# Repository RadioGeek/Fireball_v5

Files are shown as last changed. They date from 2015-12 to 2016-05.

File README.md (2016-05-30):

# Fireball_v5

<B>Compiling the Code</B>
<p>The Arduino IDE to compile and upload the code to the Fireball.  I've used the older v1.0.6 and latest
(current as of today) v1.6.8 IDE.  You will need to add the following board manager URL in the Arduino IDE Preferences, 
in order to successfully compile for the Atmel ATtiny85 processor:
https://raw.githubusercontent.com/damellis/attiny/ide-1.6.x-boards-manager/package_damellis_attiny_index.json

After you have added this to the board manager, goto Tools -> Board:, and select ATtiny at the bottom of the pulldown.
Then select the Tools menu again and you'll see additional options for Processor & Clock.
  Under the Tools -> Processor:, select ATtiny85.
  Under the Tools -> Clock:, select 8 MHz (internal)

Click the Verify button to confirm the code will compile.  If it does, you're ready to connect your AVR Programmer and
compile/upload the code.  I'm using an AVRISP mkII programmer, but I've also found my cheaper USBtinyISP purchased off
ebay worked just fine.  Sometimes you might have to select the Upload Using Programmer method, if the normal method fails.

DON'T FORGET TO BURN THE BOOTLOADER <B>BEFORE</B> UPLOADING THE CODE.</p>

<b>Config.h Settings</b>

<p>There are 3 lines in the config.h file that should be set based on user preference.</p>
<p>#define IDLE_BEEPS       true  // Enable short beeps on the second during idle time.  Set to either true or false. </p>
<p>#define SEND_CALL        true  // Enables sending of your callsign.  Set to either true or false. </p>
<p>#define CALLSIGN        "FB5"  // Operator's callsign.  Self explanatory, but can be anything less than 15 characters. </p>

<p> Have Fun with it!!!<p/>

John
AB5SS

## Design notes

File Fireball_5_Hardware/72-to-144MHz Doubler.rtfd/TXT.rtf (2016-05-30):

Design notes for constructing a 72 MHz to 144 MHz doubler

Circuit:
¬

Using 0402 SMD parts;
L = 68nH;
C (72MHz) = 72pF
C (144MHz) = 18pF

Using wire inductors and 18pf for C, calc L for 72 & 144 MHz:
Wire diameter = 0.025" & Coil Diameter = 0.25”
For 72 MHz, L = 271.5 nH; 8 turns, 0.25” length, spread for tuning;
For 144 MHz, L = 67.8 nH; 3 turns, no spacing but spread a little for tuning.

Calculator links:
http://www.daycounter.com/Calculators/Air-Core-Inductor-Calculator.phtml
http://www.1728.org/resfreq.htm

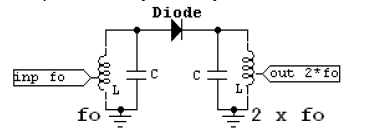
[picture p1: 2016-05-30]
Fireball_5_Hardware/72-to-144MHz Doubler.rtfd/Screen Shot 2015-04-06 at 9.13.16 AM.png

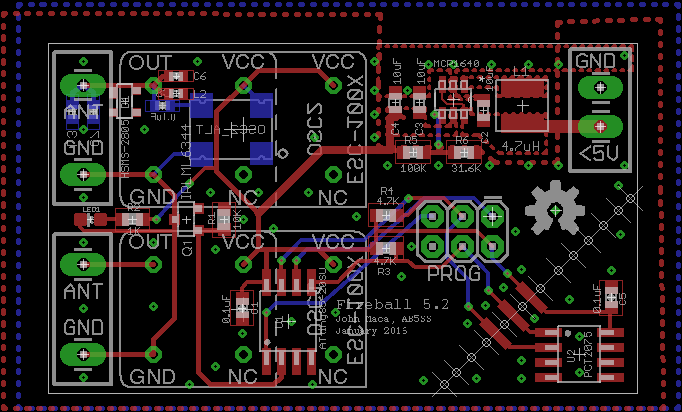
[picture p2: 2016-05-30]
Fireball_5_Hardware/Fireball_v5.2_AB5SS.brd.png

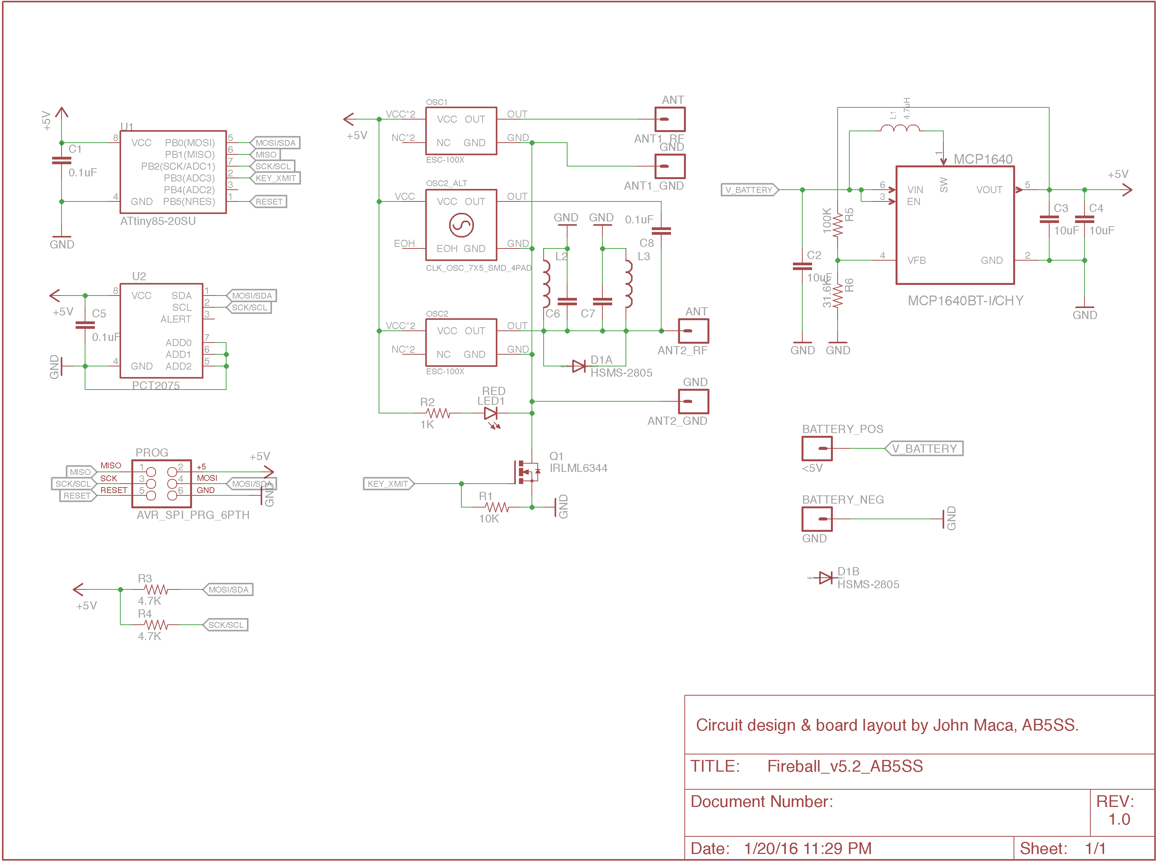
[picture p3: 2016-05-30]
Fireball_5_Hardware/Fireball_v5.2_AB5SS.sch.png

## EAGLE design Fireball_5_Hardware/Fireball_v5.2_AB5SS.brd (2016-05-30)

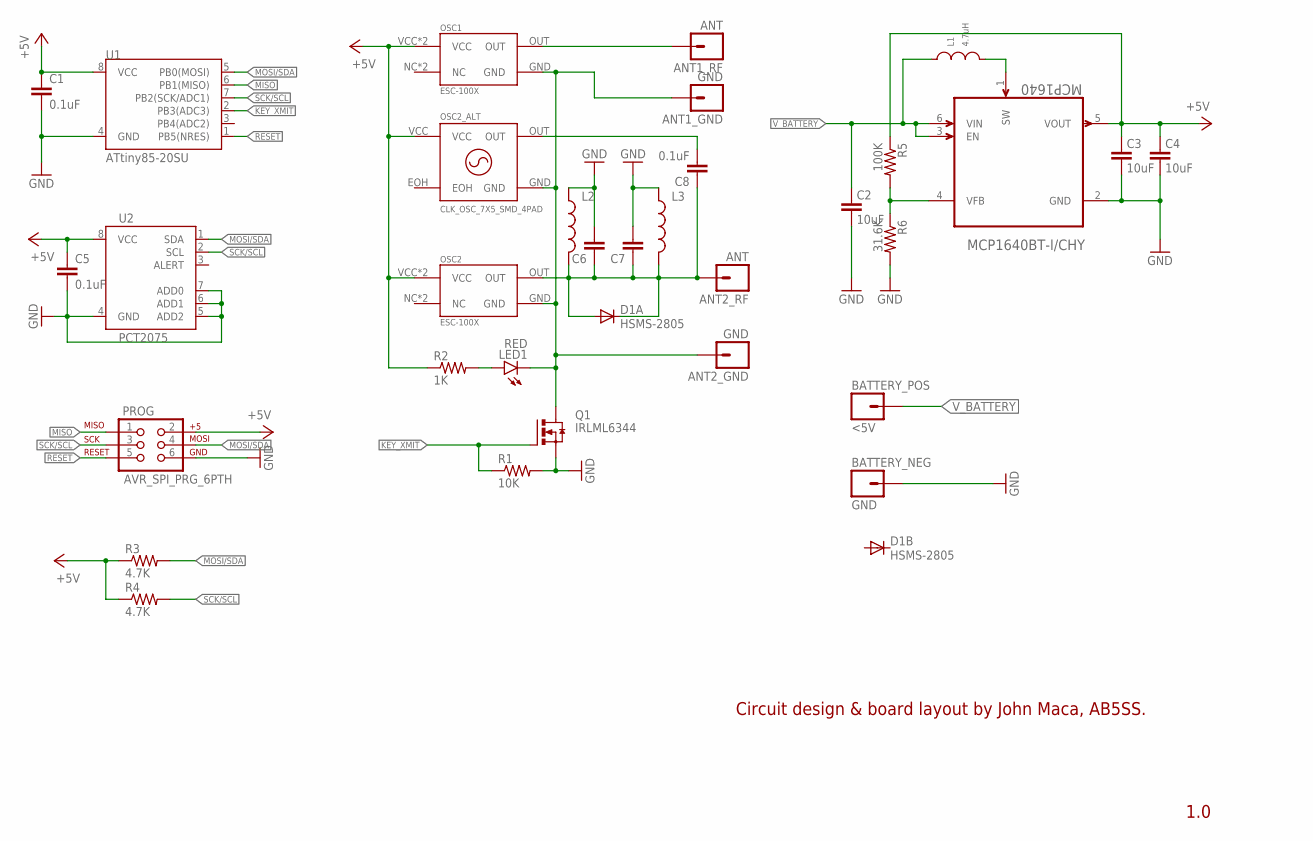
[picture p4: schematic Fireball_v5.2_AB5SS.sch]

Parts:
ANT1_GND, ANT2_GND: GND; 1X01_LONGPAD
ANT1_RF, ANT2_RF: ANT; 1X01_LONGPAD
BATTERY_NEG: GND; 1X01_LONGPAD
BATTERY_POS: <5V; 1X01_LONGPAD
C1, C5: 0.1uF; 0603-CAP
C2, C3, C4: 10uF; C603
C6, C7: CAP0402-CAP; 0402-CAP
C8: 0.1uF; 0402-CAP
D1: HSMS-2805; SOT143_AVAGO
L1: 4.7uH; SRN4026
L2, L3: INDUCTOR0402; C0402
LED1: RED; LED-0603
MCP1640: MCP1640BT-I/CHY; SOT95P270X145-6N
OSC1, OSC2: ESC-100X; OSC-20.86X13.2-4PIN
OSC2_ALT: CLK_OSC_7X5_SMD_4PAD; CLK_OSC_7.00X5.00_SMD-4PAD
PROG: AVR_SPI_PRG_6PTH; 2X3
Q1: IRLML6344; MICRO3
R1: 10K; 0603-RES
R2: 1K; 0603-RES
R3, R4: 4.7K; 0603-RES
R5: 100K; 0603-RES
R6: 31.6K; 0603-RES
U1: ATtiny85-20SU; SO08-EIAJ
U2: PCT2075; SO08

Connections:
+5V: C1.1, C3.1, C4.1, C5.1, MCP1640.5 (VOUT), OSC1.VCC, OSC1.VCC2 (VCC), OSC2.VCC, OSC2.VCC2 (VCC), OSC2_ALT.VCC, PROG.2, R2.1, R3.1, R4.1, R5.1, U1.8 (VCC), U2.8 (VCC)
GND: BATTERY_NEG.1, C1.2, C2.2, C3.2, C4.2, C5.2, C6.2, C7.2, L2.1, L3.1, MCP1640.2 (GND), PROG.6, Q1.2 (S), R1.2, R6.2, U1.4 (GND), U2.4 (GND), U2.5 (ADD2), U2.6 (ADD1), U2.7 (ADD0)
KEY_XMIT: Q1.1 (G), R1.1, U1.2 (PB3(ADC3))
L1_SW: L1.P$2 (2), MCP1640.1 (SW)
MISO: PROG.1, U1.6 (PB1(MISO))
MOSI/SDA: PROG.4, R3.2, U1.5 (PB0(MOSI)), U2.1 (SDA)
unnamed: ANT1_GND.1, ANT2_GND.1, LED1.C, OSC1.GND, OSC2.GND, OSC2_ALT.GND, Q1.3 (D)
unnamed: MCP1640.4 (VFB), R5.2, R6.1
unnamed: LED1.A, R2.2
unnamed: ANT1_RF.1, OSC1.OUT
unnamed: ANT2_RF.1, C6.1, C7.1, C8.1, D1.1 (C), D1.3 (A), L2.2, L3.2, OSC2.OUT
unnamed: C8.2, OSC2_ALT.OUT
RESET: PROG.5, U1.1 (PB5(NRES))
SCK/SCL: PROG.3, R4.2, U1.7 (PB2(SCK/ADC1)), U2.2 (SCL)
V_BATTERY: BATTERY_POS.1, C2.1, L1.P$1 (1), MCP1640.3 (EN), MCP1640.6 (VIN)

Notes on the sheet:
1.0
Circuit design & board layout by John Maca, AB5SS.

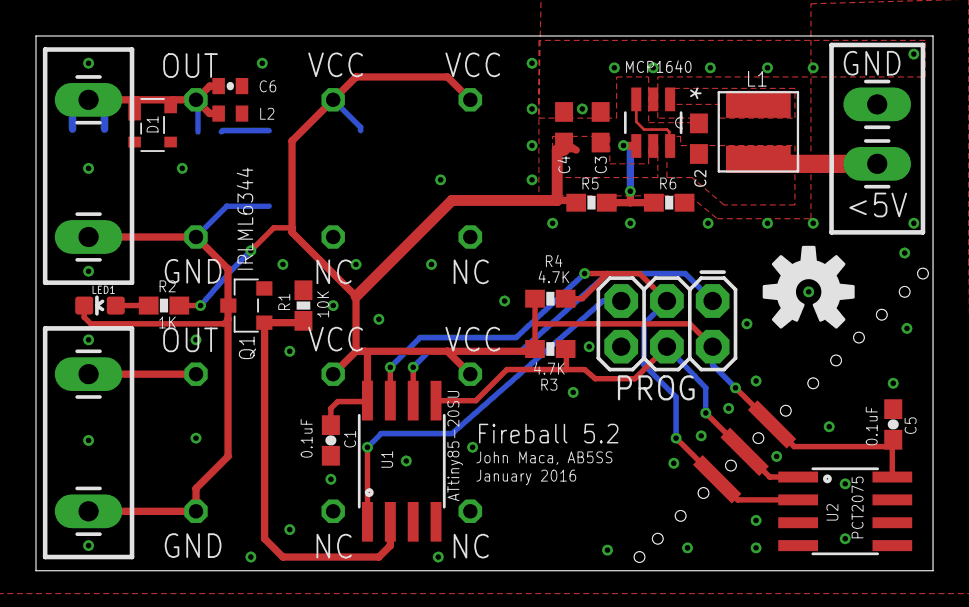
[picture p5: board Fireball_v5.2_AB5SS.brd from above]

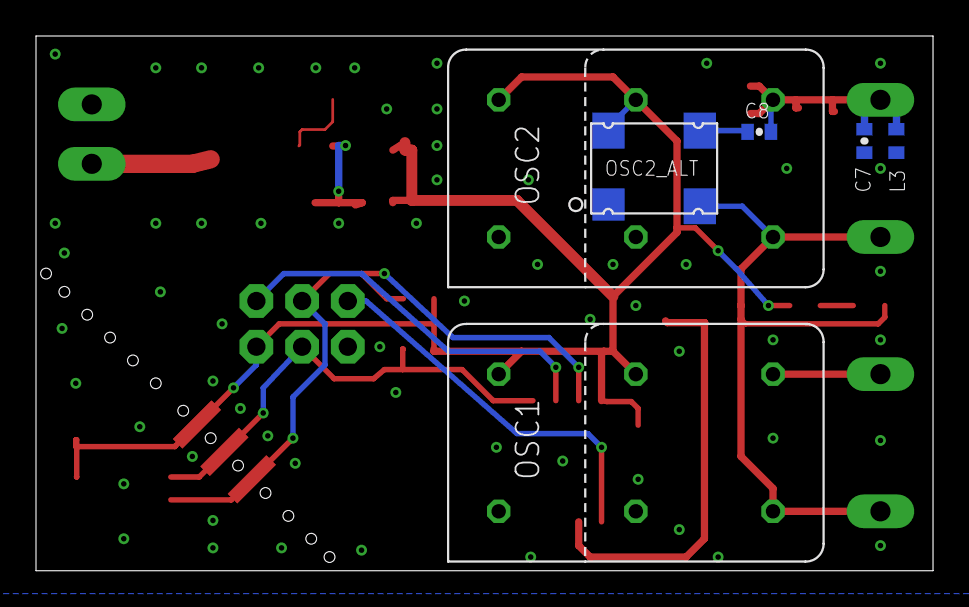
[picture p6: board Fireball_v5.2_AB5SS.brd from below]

Board: 2 copper layers, 49.8 x 29.7 mm, 34 parts (6 on the bottom side), 15 nets.

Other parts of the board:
U$1: OSHW-LOGO-M

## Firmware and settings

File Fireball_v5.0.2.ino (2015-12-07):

// ==========================================================================================//
// Fireball v5.0 source code 
// Copyright 2015 by John Maca, AB5SS, all rights reserved.
//
// This code was written for a 'digital' version of the "Fireball" class of QRP transmitters
// that I designed and built for fun.  This Fireball v5.x design was my attempt to try and 
// improve on the analog 555 timer based Fireball transmitters that Andy MacAllister, W5ACM, 
// and others have built and launched on short duration high altitude balloon flights. 
// I will likely release this code as open source in the future, but for now it remains 
// closed.  See other libraries for rights associated with their distribution & use. 
//
// This version uses an Atmel ATtiny85 microcontroller running at 8MHz, an NXP PCT2075 
// (equivalent to the TI LM75A) digital temperature sensor, TI TPS61202 5V Boost power 
// converter/supply, and up to two (2) standard 5V clock oscillators the builder chooses to 
// use.  Although not yet implmented, I'm leaving scars in this code for other/different sensors, 
// including a pressure/temp sensor (like the Bosch BMP180), or effectors (like an ultra-bright 
// LED pointing toward the ground).  
//
// This version of the software periodically transmits the temperature (deg C/F) in Morse code
// the operators amatuer radio callsign, and optionally will transmit 'idle' beeps in between
// temperature transmissions. 
//
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
// Include Files
#include <ctype.h>
#include <Arduino.h>
#include <avr/sleep.h>
#include <avr/power.h>
#include <avr/wdt.h>
#include "TinyWireM.h"
#include "config.h"
#include "morse.h"


// Variables declarations
  int   TempC = 0;
  int   TempF = 0;

// ==========================================================================================//

// Watchdog Interrupt Service is executed when watchdog times out
ISR(WDT_vect) {}

// Function to put AT85 to power down for 1 second
//
void power_down_1s()
{
  unsigned char mcucr1, mcucr2;
  ACSR |= _BV(ACD);                         //disable the analog comparator
  ADCSRA &= ~_BV(ADEN);                     //disable ADC
  set_sleep_mode(SLEEP_MODE_PWR_DOWN);
  sleep_enable();
  wdtEnable();    // Sets WDT for 1 second
  cli();
  mcucr1 = MCUCR | _BV(BODS) | _BV(BODSE);  //turn off the brown-out detector
  mcucr2 = mcucr1 & ~_BV(BODSE);
  MCUCR = mcucr1;
  MCUCR = mcucr2;
  sei();        //ensure interrupts enabled so we can wake up again
  sleep_cpu();  // Power down cpu
  cli();
  sleep_disable();
  wdtDisable();
  sei();
  power_all_enable();
}

void wdtEnable(void)
{
    wdt_reset();
    cli();
    MCUSR = 0x00;
    WDTCR |= _BV(WDCE) | _BV(WDE);
    WDTCR  = _BV(WDP2) | _BV(WDP1) ;    // 1 sec
    WDTCR |= _BV(WDIE);
    sei();
}

//disable the wdt
void wdtDisable(void)
{
    wdt_reset();
    cli();
    MCUSR = 0x00;
    WDTCR |= _BV(WDCE) | _BV(WDE);
    WDTCR = 0x00;
    sei();
}

                                                                                                                                                                                                    
// Function: GetTemp() - Gets the temperature from the PCT2075 and stores it in 
//   variables TempNeg (true if temp < 0) and TempAbs (the absolute temp).
//
void GetTemp() {
  byte TempMSB, TempLSB;
  
  // Get Temperature
  TinyWireM.beginTransmission(PCT2075_ADDRESS);
  TinyWireM.requestFrom(PCT2075_ADDRESS, 2);
  TempMSB = TinyWireM.receive();
  TempLSB = TinyWireM.receive();
  TinyWireM.endTransmission();

//  TempMSB = 0xEF;  // TEST values 
//  TempLSB = 0x00;
  
  if (TempMSB > 0x7F) { 
    TempC = -(float((TempMSB ^ 0xFF) + 0x01));  // Convert 2's compliment negative number 
    if (TempLSB & 0x80 == 0x80) {
      TempC = TempC - 0.5;
    }
    if (TempLSB & 0x40 == 0x40) {
      TempC = TempC - 0.25;
    }  
    if (TempLSB & 0x20 == 0x20) {
      TempC = TempC - 0.125;
    }
  }
  else {
    TempC = float(TempMSB);
    if (TempLSB & 0x80 == 0x80) {
      TempC = TempC + 0.5;
    }
    if (TempLSB & 0x40 == 0x40) {
      TempC = TempC + 0.25;
    }  
    if (TempLSB & 0x20 == 0x20) {
      TempC = TempC + 0.125;
    }
  }
  TempF = round((TempC * 9 / 5) + 32.0); 
  TempC = round(TempC);
}

// Function to Enable/Shutdown the PCT2075
// Pass 0x00 for Enable and 0x01 for Shutdown
void set_PCT2075_config(byte reg_value)
{
  TinyWireM.beginTransmission(PCT2075_ADDRESS);
  TinyWireM.send(1); // Select Configuration register
  TinyWireM.send(reg_value);
  TinyWireM.endTransmission();
} 

// Function: SendTempC() - Sends the temperature in degrees C
//
void SendTempC() {
  char TempStr[6];
  
  itoa(int(TempC), TempStr, 10);
  
  for (int i=0; i < strlen(TempStr); i++) {
    SendMorse(TempStr[i]);
  }
  SendMorse('C');  
}

// Function: SendTempF() - Sends the temperature in degrees F
//
void SendTempF() {
  char TempStr[6];
  
  itoa(int(TempF), TempStr, 10);
  
  for (int i=0; i < strlen(TempStr); i++) {
    SendMorse(TempStr[i]);
  }
  SendMorse('F');  
}
    
// Function: SendCallsign() - Sends the Operator's callsign defined in config.h
//
void SendCallsign() {
  if (SEND_CALL == true) {
    char callstr[15] = CALLSIGN;
    SendMorse('D');
    SendMorse('E');
    SendMorse(' ');
    for (int i=0; i < strlen(callstr); i++) {
      SendMorse(callstr[i]);
    }
  }
  EndOfWord();
} 

// Function: SendIdleBeeps(beeps, beep_spacing) - where t is the number of seconds between beeps. Adjust 
//   for your microcontrollers true amount of delay.
//  
void SendIdleBeeps(int beeps, int beep_spacing) {
  if (IDLE_BEEPS == true) {
    delay(1100);
    for (int i=1; i <= beeps; i++) {
      digitalWrite (XMIT_PIN, HIGH);
      delay (150);
      digitalWrite (XMIT_PIN, LOW); 
//      delay (1100 * beep_spacing);
      for (int j=1; j <= beep_spacing; j++) {
        power_down_1s();
      }
    }
  }
}


void setup() {
  pinMode(XMIT_PIN, OUTPUT);   // initialize the digital pin as an output.
  TinyWireM.begin();           // initialize I2C bus.
//  set_PCT2075_config(PCT2075_SHUTDOWN);   // Shutdown PCT2075 Temperature Sensor to conserve power
  delay(2000);
}

void loop() { 
  SendCallsign();       // Will send callsign if #define SEND_CALL is set to 'true'
  for (byte i=0; i<10; i++) {  //  Loop i times.  Change code later to use millis() function in SendCallsign().  
    GetTemp();
    SendTempC();
    delay(1000);
    SendTempF();
    SendIdleBeeps(4, 5);  // Will send idle beeps if #define IDLE_BEEPS set to 'true'; e.g. 4 beeps, 5 seconds apart.
  }
}

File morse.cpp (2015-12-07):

// ==========================================================================================//
// Fireball v5.0 source code 
// Copyright 2015 by John Maca, AB5SS, all rights reserved.
// ==========================================================================================//
//
// This module contains the functions to send the messages using Morse code.
//

#include <Arduino.h>
#include "config.h"
#include "morse.h"

void dot() {
  digitalWrite (XMIT_PIN, HIGH);
  delay (dotLength);
  digitalWrite (XMIT_PIN, LOW); 
  delay (dotLength);
} 

void dash() {
  digitalWrite (XMIT_PIN, HIGH);
  delay (dashLength);
  digitalWrite (XMIT_PIN, LOW); 
  delay (dotLength);
}

void EndOfChar() {
  delay (pauseChar);
}

void EndOfWord() {
  delay (pauseWord);
}

void SendMorse(char tmpChar) {
  if (isalpha(tmpChar)) {
    tmpChar = toupper(tmpChar);
  }
  switch (tmpChar) {
    case '0': {
      dash(); dash(); dash(); dash(); dash(); }
      break;
    case '1': {
      dot(); dash(); dash(); dash(); dash(); }
      break;
    case '2': {
      dot(); dot(); dash(); dash(); dash(); }
      break;
    case '3': {
      dot(); dot(); dot(); dash(); dash(); }
      break;
    case '4': {
      dot(); dot(); dot(); dot(); dash(); }
      break;
    case '5': {
      dot(); dot(); dot(); dot(); dot(); }
      break;      
    case '6': {
      dash(); dot(); dot(); dot(); dot(); }
      break;
    case '7': {
      dash(); dash(); dot(); dot(); dot(); }
      break;      
    case '8': {
      dash(); dash(); dash(); dot(); dot(); }
      break; 
    case '9': {
      dash(); dash(); dash(); dash(); dot(); }
      break;  
    case 'A': {
      dot(); dash(); }
      break;    
    case 'B': {
      dash(); dot(); dot(); dot(); }
      break;    
    case 'C': {
      dash(); dot(); dash(); dot(); }
      break;    
    case 'D': {
      dash(); dot(); dot(); }
      break;    
    case 'E': {
      dot(); }
      break;    
    case 'F': {
      dot(); dot(); dash(); dot();  }
      break;    
    case 'G': {
      dash(); dash(); dot(); }
      break;    
    case 'H': {
      dot(); dot(); dot(); dot();  dot(); }
      break;    
    case 'I': {
      dot(); dot(); }
      break;    
    case 'J': {
      dot(); dash(); dash(); dash(); }
      break;    
    case 'K': {
      dash(); dot();  dash(); }
      break;    
    case 'L': {
      dot(); dash(); dot(); dot(); }
      break;    
    case 'M': {
      dash(); dash(); }
      break;    
    case 'N': {
      dash(); dot(); }
      break;    
    case 'O': {
      dash(); dash(); dash(); }
      break;    
    case 'P': {
      dot(); dash(); dash(); dot(); }
      break;    
    case 'Q': {
      dash(); dash(); dot(); dash(); }
      break;    
    case 'R': {
      dot();  dash(); dot(); }
      break;    
    case 'S': {
      dot(); dot(); dot(); }
      break;    
    case 'T': {
      dash(); }
      break;    
    case 'U': {
      dot(); dash(); dash(); }
      break;    
    case 'V': {
      dot(); dot(); dot(); dash(); }
      break;    
    case 'W': {
      dot(); dash(); dash(); }
      break;    
    case 'X': {
      dash(); dot(); dot(); dash(); }
      break;    
    case 'Y': {
      dash(); dot(); dash(); dash(); }
      break;
    case 'Z': {
      dash(); dash(); dot(); dot(); }
      break;  
    case ' ': {
      EndOfChar(); }
      break;  
    case '-': {
      dash(); dot(); dot(); dot(); dot(); dash();  }
      break;  
    case '.': {
      dot(); dash(); dot(); dash(); dot(); dash();  }
      break;  
    case '/': {
      dash(); dot(); dot(); dash(); dot(); }
      break;  
    case '?': {
      dot(); dot(); dash(); dash(); dot(); dot(); }
      break;  
    default: {
      dot(); dot(); dash(); dash(); dot(); dot(); }
  }
  EndOfChar();
}

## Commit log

2015-12-07 Fireball v5 Transmitter
    The Fireball v5 is transmits the temperature in C & F in Morse code.
2016-05-30 Merge branch 'master' into config-update
    Major change to add hardware files, including the EagleCAD 7 Gerber
    files. Also the design & part values for the 72 to 144 MHz doubler.
    [Fireball_v5.2_AB5SS.brd, Fireball_v5.2_AB5SS.sch]

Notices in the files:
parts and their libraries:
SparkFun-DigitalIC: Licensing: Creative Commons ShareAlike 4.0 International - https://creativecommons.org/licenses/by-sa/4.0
